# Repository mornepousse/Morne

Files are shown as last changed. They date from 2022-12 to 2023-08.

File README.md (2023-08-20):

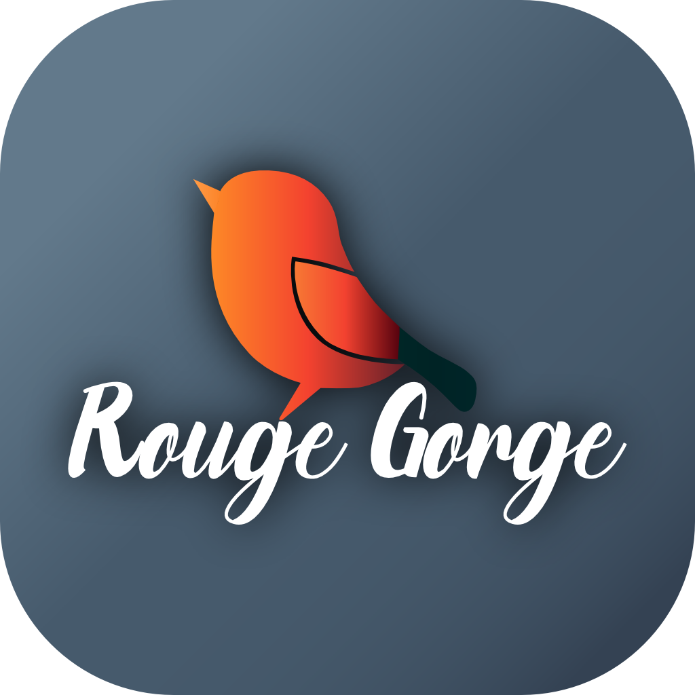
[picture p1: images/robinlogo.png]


The keyboard I created is a derivative of the Jorne and Kyria rev2, two keyboards highly appreciated in the community of mechanical keyboard enthusiasts. I took the best for me.

fr : Le clavier que j'ai créé est un dérivé du Jorne et du Kyria rev2, deux claviers très appréciés dans la communauté des amateurs de claviers mécaniques. J'ai pris le meilleur pour moi.

Update: 

Currently, I have not yet had the time to test the PCB and create the QMK code.

Actuellement, je n'ai pas encore eu le temps de tester le PCB et de créer le code QMK.

## PCB

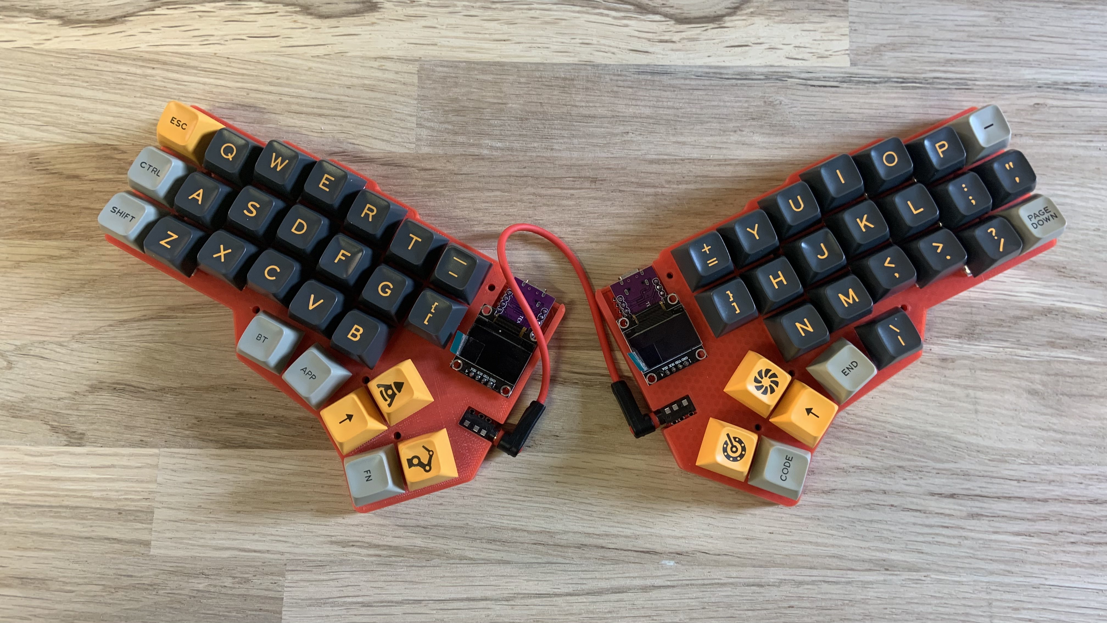
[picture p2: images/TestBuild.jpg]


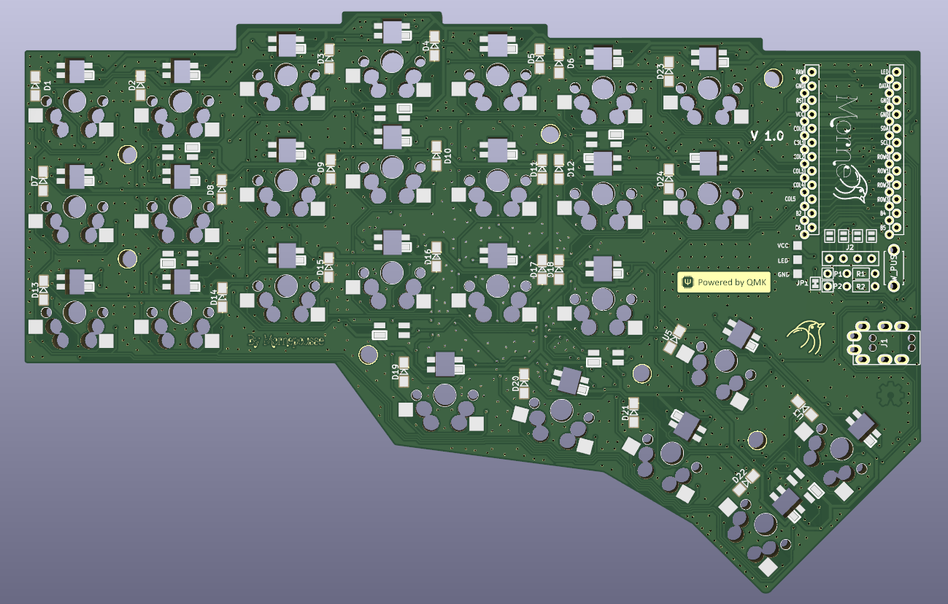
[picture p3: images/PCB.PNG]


Creation date: 02/12/2022

By ordering on [JLCPCB](https://cart.jlcpcb.com/quote?orderType=1&stencilLayer=2&stencilWidth=100&stencilLength=100&stencilCounts=5):

x 5 = 10.60$

u = 2.12$ x 2 = 4.24$

| Id | Reference | Package | Quantity | Designation | Supplier and ref | Ali price |
|----|---|---|---|---|---|---|
| 1  | D1,D2,D3...| Diode_TH_SOD123EKR | 26 | D |  [aliexpress](https://fr.aliexpress.com/item/1005003631407506.html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) , [TME](https://www.tme.eu/fr/details/1n5711w-7-f/diodes-schottky-smd/diodes-incorporated/) | 0.0546€ x 26 = 1.42€ |
| 2  | L1,L2,L3...| SK6812MINI_rev | 26 | SK6812MINI |  [aliexpress](https://fr.aliexpress.com/item/1005003021596311.html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) | 0.0704€ x 26 = 1.83€ |
| 3  | SW1,SW2,SW3...| MX_Socket_18mm | 26 | SW_PUSH | [aliexpress](https://fr.aliexpress.com/item/1005003873653184.html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)  | 0.1285€ x 26 = 3.34€ |
| 5  | U1 | ProMicro_v2 | 1 | ProMicro | [aliexpress](https://fr.aliexpress.com/item/1005003622414316.html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)  | 6.155€ |
| 8  | JP1 | JPC2 | 1 |  1X4Pin | [aliexpress](https://fr.aliexpress.com/item/4000979967513.html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)  | 0.182€ |
| 9  | J2 | OLED | 1 | OLED |  [aliexpress](https://fr.aliexpress.com/item/33024849277.html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) | 3.10€ |
| 10 | J1 | MJ-4PP-9 | 1 | MJ-4PP-9 |  [aliexpress](https://fr.aliexpress.com/item/33029465106.html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) | 0.246€ |
| 11 | RSW1 | ResetSW | 1 | SW_PUSH | [aliexpress](https://fr.aliexpress.com/item/1005004067514307.html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)  | 0.137€ |
| 12 | L22,L23,L24... | SK6812MINI_underglow_rev | 7 | SK6812MINI |  [aliexpress](https://fr.aliexpress.com/item/1005003021596311.html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) | 0.0704€ x 7 = 0.49€ |

Total price : 16.45€ x 2 = 32.90€

Other Parts:
| Name | links |
|---|---|
| Jack TRRS cable | [ali1](https://fr.aliexpress.com/item/1005003415667083.html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) [ali2](https://fr.aliexpress.com/item/33006667627.html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) [ali3](https://fr.aliexpress.com/item/1005002888851426.html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) |
| Switchs | [ali1](https://fr.aliexpress.com/item/1005003436102892.html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), [ali Khail Cream](https://fr.aliexpress.com/item/1005003694230110.html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) |
| Keycaps | [AF SA](https://fr.aliexpress.com/item/1005003935785708.html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), [cerise](https://fr.aliexpress.com/item/1005003932690197.html?gatewayAdapt=glo2fra) |

Simulate the final price (case not included):

| PCB | SMDs | Switchs | Keycaps[?](https://fr.aliexpress.com/item/1005003935785708.html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) | Total |
|---|---|---|---|---|
| 3.97€ | 32.90€ | 18.06€ | 48.98€ | 103.91€ |

[BOM](https://github.com/mornepousse/Morne/blob/jorne/doc/BOM.md)

[Firmware](https://github.com/mornepousse/Rouge-Gorge_QMX_Part)

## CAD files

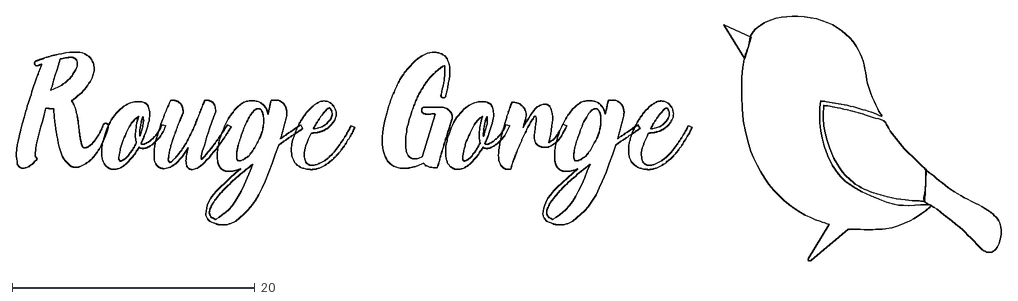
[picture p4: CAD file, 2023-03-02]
other/morne logo txt.dxf
81.2 x 20.2

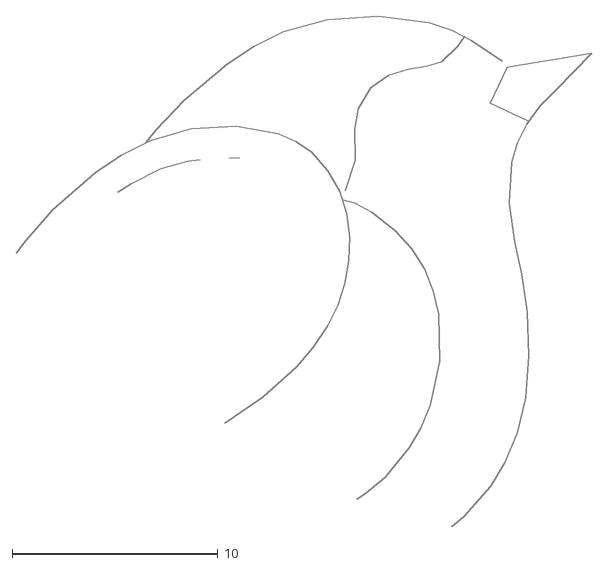
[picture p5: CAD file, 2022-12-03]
other/morne logo.dxf
28.0 x 24.8

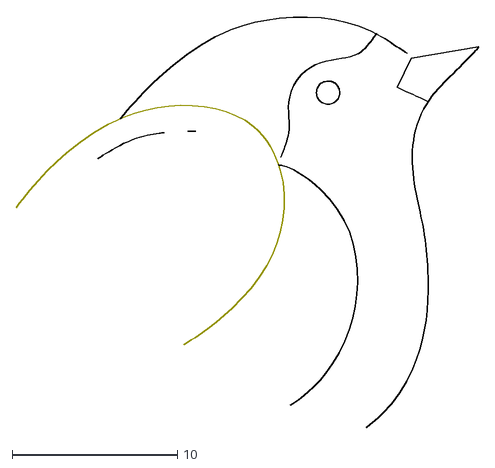
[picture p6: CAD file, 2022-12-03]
other/morne logo14.dxf
28.0 x 24.9

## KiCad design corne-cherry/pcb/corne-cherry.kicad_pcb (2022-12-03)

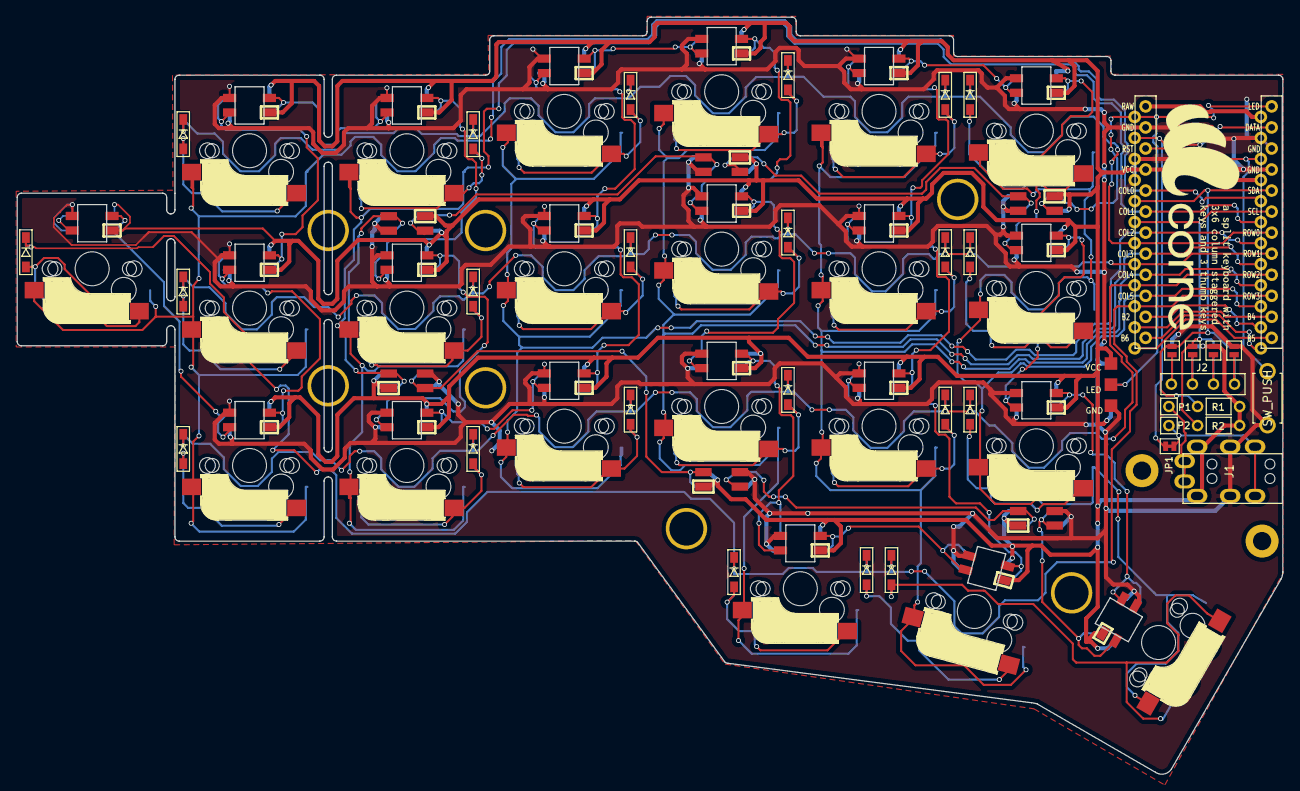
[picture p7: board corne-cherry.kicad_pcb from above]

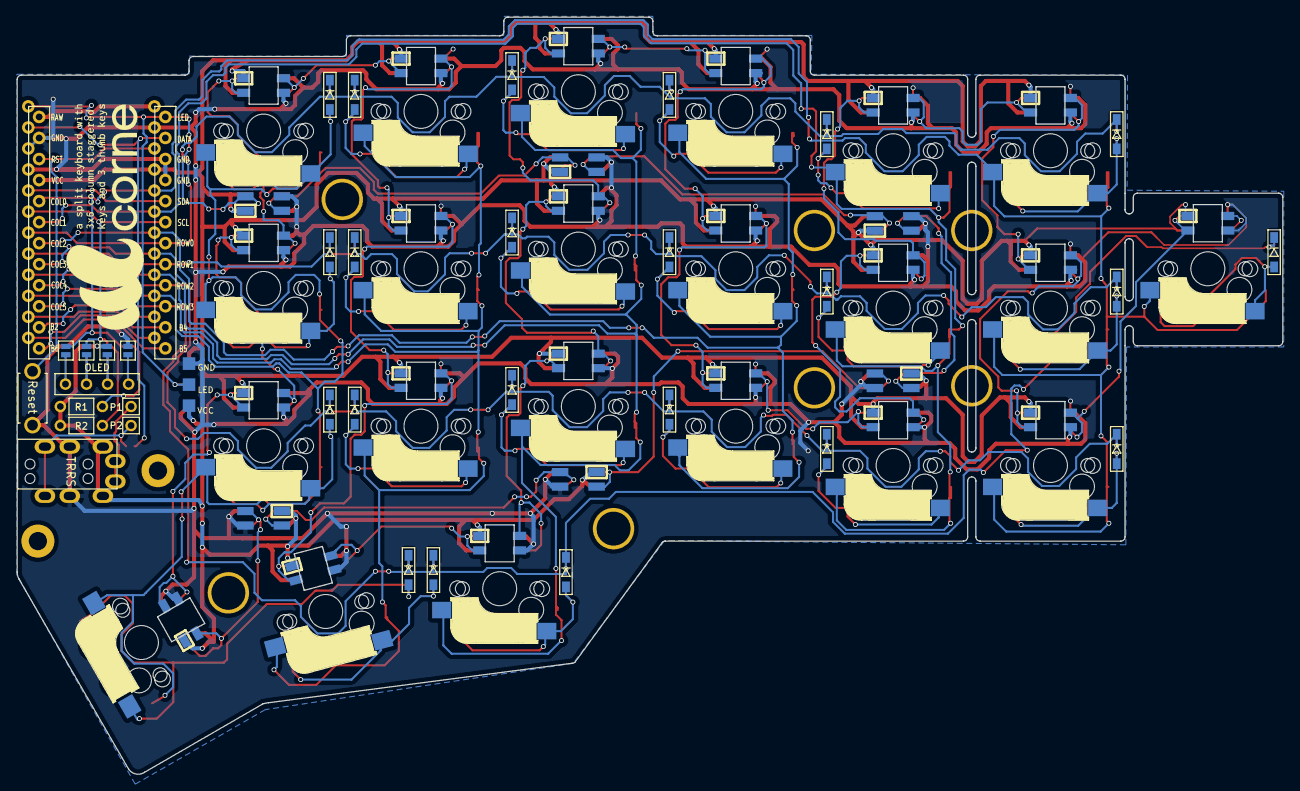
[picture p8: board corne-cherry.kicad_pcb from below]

Board: 2 copper layers, 152.8 x 91.4 mm, 101 parts (5 on the bottom side), 72 nets.

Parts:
D1, D2, D3, D4, D5, D6, D7, D8, D9, D10, D11, D12, D13, D14, D15, D16, D17, D18, D19, D20, D21, D22: D; D3_SMD
G01, G02: Logo_Open_Hardware_Small; corne
H1, H2, H3, H4, H5, H6, H7, H8, H9: MountingHole; LEGO_HOLE
J1: MJ-4PP-9
J2: OLED
J3: LED; StripLED_rev
JP1: JPC2
JP2, JP3, JP4, JP5, JP6, JP7, JP8, JP9: Jumper
L1, L2, L3, L4, L5, L6, L7, L8, L9, L10, L11, L12, L13, L14, L15, L16, L17, L18, L19, L20, L21, L28: SK6812MINI; SK6812MINI_rev
L22, L23, L24, L25, L26, L27: SK6812MINI; SK6812MINI_underglow_rev
P1, P2: i2c-pin; 1pin_conn
R1, R2: R
RSW1: SW_PUSH; ResetSW
SW1, SW2, SW3, SW4, SW5, SW6, SW7, SW8, SW9, SW10, SW11, SW12, SW13, SW14, SW15, SW16, SW17, SW18, SW19, SW20, SW22: SW_PUSH; CherryMX_MidHeight_Hotswap
SW21: SW_PUSH; CherryMX_MidHeight_Hotswap_1.5u
U1: ProMicro; ProMicro_v2

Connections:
GND: J1.C, J3.1, JP2.1, JP9.1, L1.2, L2.2, L3.2, L4.2, L5.2, L6.2, L7.2, L8.2, L9.2, L10.2, L11.2, L12.2, L13.2, L14.2, L15.2, L16.2, L17.2, L18.2, L19.2, L20.2, L21.2, L22.2, L23.2, L24.2, L25.2, L26.2, L27.2, L28.2, RSW1.2, U1.3, U1.4, U1.23
LED: J3.2, L24.3, U1.1
unnamed: D1.2, SW1.2
unnamed: D2.2, SW2.2
unnamed: D3.2, SW3.2
unnamed: D4.2, SW4.2
unnamed: D5.2, SW5.2
unnamed: D6.2, SW6.2
unnamed: D7.2, SW7.2
unnamed: D8.2, SW8.2
unnamed: D9.2, SW9.2
unnamed: D10.2, SW10.2
unnamed: D11.2, SW11.2
unnamed: D12.2, SW12.2
unnamed: D13.2, SW13.2
unnamed: D14.2, SW14.2
unnamed: D15.2, SW15.2
unnamed: D16.2, SW16.2
unnamed: D17.2, SW17.2
unnamed: D18.2, SW18.2
unnamed: D19.2, SW19.2
unnamed: D20.2, SW20.2
unnamed: D21.2, SW21.2
unnamed: D22.2, SW22.2
unnamed: J1.A, P1.1
unnamed: J1.B, JP1.2, P2.1
unnamed: J2.1, JP5.2, JP9.2
unnamed: J2.2, JP4.2, JP8.2
unnamed: J2.3, JP3.2, JP7.2
unnamed: J2.4, JP2.2, JP6.2
unnamed: L1.1, L7.3
unnamed: L1.3, L2.1
unnamed: L2.3, L8.1
unnamed: L3.1, L9.3
unnamed: L3.3, L4.1
unnamed: L5.3, L6.1
unnamed: L4.3, L10.1
unnamed: L10.3, L16.1
unnamed: L11.1, L17.3
unnamed: L5.1, L11.3
unnamed: L6.3, L12.1
unnamed: L12.3, L18.1
unnamed: L13.1, L28.3
unnamed: L7.1, L13.3
unnamed: L8.3, L14.1
unnamed: L14.3, L15.1
unnamed: L9.1, L15.3
unnamed: L16.3, L19.1
unnamed: L17.1, L20.3
unnamed: L18.3, L21.1
unnamed: L19.3, L20.1
unnamed: L21.3, L27.1
unnamed: L22.1, L25.3
unnamed: L22.3, L23.1
unnamed: L23.3, L24.1
unnamed: L25.1, L26.3
unnamed: L26.1, L27.3
SCL: JP4.1, JP7.1, R2.2, U1.6
SDA: JP5.1, JP6.1, R1.2, U1.5
VCC: J1.D, J3.3, JP3.1, JP8.1, L1.4, L2.4, L3.4, L4.4, L5.4, L6.4, L7.4, L8.4, L9.4, L10.4, L11.4, L12.4, L13.4, L14.4, L15.4, L16.4, L17.4, L18.4, L19.4, L20.4, L21.4, L22.4, L23.4, L24.4, L25.4, L26.4, L27.4, L28.4, R1.1, R2.1, U1.21
col0: SW1.1, SW7.1, SW13.1, SW22.1, U1.20
col1: SW2.1, SW8.1, SW14.1, U1.19
col2: SW3.1, SW9.1, SW15.1, U1.18
col3: SW4.1, SW10.1, SW16.1, SW19.1, U1.17
col4: SW5.1, SW11.1, SW17.1, SW20.1, U1.16
col5: SW6.1, SW12.1, SW18.1, SW21.1, U1.15
data: JP1.1, U1.2
reset: RSW1.1, U1.22
row0: D1.1, D2.1, D3.1, D4.1, D5.1, D6.1, U1.7
row1: D7.1, D8.1, D9.1, D10.1, D11.1, D12.1, U1.8
row2: D13.1, D14.1, D15.1, D16.1, D17.1, D18.1, U1.9
row3: D19.1, D20.1, D21.1, D22.1, U1.10

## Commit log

2019-07-14 fixed corne-cherry outlines
    [corne-cherry.kicad_pcb]
2019-07-14 added zones, fixed silk
    [corne-classic.kicad_pcb]
2019-07-14 fixed schematic
    [corne-classic.kicad_pcb, corne-classic.sch]
2019-07-14 added gerbers and download links
2019-08-15 added drawings
    [corne-cherry.kicad_pcb, corne-cherry.sch, tilting-tenting-jorne.dxf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]
2019-08-15 updated drawings
    [tilting-tenting-jorne.dxf, top-bottom-jorne.dxf]
2019-08-17 updated dxf
    [tilting-tenting-jorne.dxf, top-bottom-jorne.dxf]
2019-08-17 added quote
    [tilting-tenting-jorne.dxf, top-bottom-jorne.dxf]
2019-08-18 updated gerbers
2019-08-21 removed combined boards because jlcpcb sucks
2019-08-21 updated corne-cherry
    [corne-cherry.kicad_pcb]
2019-08-21 updated jorne-classic-2.1
    [corne-classic.kicad_pcb]
2019-08-24 added metal plate
2019-08-27 added BOM
2019-08-27 added tilting-tenting-jorne-half
    [tilting-tenting-jorne-half.dxf]
2019-08-27 updated files
    [tilting-tenting-jorne-half.dxf]
2019-08-27 fixed jorne-simple.dxf
    [jorne-simple.dxf]
2019-08-28 fixed dxf
    [jorne-tilted.dxf]
2019-09-16 fixed LED holes in corne-cherry 2.1
    [corne-cherry.kicad_pcb]
2019-09-17 removed link to nrfmicro gerbers
2019-09-17 removed nrfmicro gerber (no led hole)
2019-09-24 added steel plates with 14.00 mm cutouts
    [jorne-simple-metal-plate.dxf, jorne-tilted-metal-plate.dxf]
2019-11-29 updated jorne-simple.dxf
    [jorne-simple.dxf]
2020-01-07 added PCB top plate
    [corne-top-plate.kicad_pcb]
2020-01-07 added gerbers
2020-01-08 added bottom plate
    [corne-bottom-plate.kicad_pcb]
2020-01-08 updated jorne-tilted.dxf, added pictures
    [jorne-tilted.dxf]
2020-07-10 added case.stl
    [case.stl]
2020-07-16 added stl and stp files
    [jorne_tilted_case_complete.stp, jorne_tilted_case_complete_3dp.stl]
2020-07-24 removed old stl
    [case.stl, jorne_tilted_case_complete.stp, jorne_tilted_case_complete_3dp.stl]
2020-10-17 Added jorne-cherry-3.0
    [corne-cherry.kicad_pcb, corne-cherry.kicad_sch]
2020-11-15 Update README.md
    add 3D print case
2020-12-15 added jorne.blend
    [jorne.blend]
2020-12-16 fixed units
    [jorne.blend]
2020-12-16 fixed outlines for pcb plates
    [corne-bottom-plate.kicad_pcb, corne-top-plate.kicad_pcb, jorne.blend]
2020-12-18 fixed geometry
    [jorne.blend, jorne.stl]
2020-12-18 fixed cutouts (note halves are asymmetrical!)
    [jorne.blend, jorne.stl]
2020-12-18 fixed non-manifold
    [jorne.blend, jorne.stl]
2020-12-19 3d case released, left and right halves
    [jorne.blend, jorne.stl, jorne_left.blend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]
2020-12-19 fixed tab size of the pinky key
    [corne-classic.kicad_pcb]
2021-07-19 Added Jorne Wireless PCB files
    [corne-cherry-left.kicad_pcb, corne-cherry-left.sch, corne-cherry-right.kicad_pcb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]
2021-07-19 Added top and bottom plates with breakoff pinkies to match the Jorne-WL PCB
    [corne-bottom-plate-breakoff.kicad_pcb, corne-top-plate-breakoff.kicad_pcb]
2021-08-24 Two solder pads for 'p' and ';' were unrouted
    [corne-cherry-right.kicad_pcb]
2021-08-29 added plated plate
    [corne-top-plate-breakoff-plated.kicad_pcb]
2021-10-03 Small revision bump: bigger battery header, smaller footprints
    [corne-cherry-left.kicad_pcb, corne-cherry-left.sch, corne-cherry-right.kicad_pcb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]
2021-12-27 added jorne hi-pro m5 with tenting
    [Jorne Hi-Pro with m5 tenting v1.stl]
2022-12-03 Clean
    Clean up
    [Jorne Hi-Pro with m5 tenting v1.stl, corne-bottom-plate-breakoff.kicad_pcb, corne-bottom-plate.kicad_pcb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]
2022-12-03 V1 morne
    [corne-cherry.kicad_sch, jorne-simple-bottom.dxf, jorne-simple-metal-plate.dxf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]
2023-02-12 Addition of the preliminary BOM
2023-02-12 Add Simulate the final price (case not included)
2023-02-12 add keycaps in BOM.md
2023-02-22 Add PCB image
2023-03-02 Correction Led - new Logo
    [corne-cherry.kicad_sch, morne logo txt.dxf]
